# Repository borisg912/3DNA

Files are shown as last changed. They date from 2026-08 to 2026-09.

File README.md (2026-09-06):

# 3DNA - Interactive DNA Learning Model

**3DNA** is an educational 3D-printed DNA model that combines physical structure with interactive electronics to help students understand DNA base pairing through hands-on learning.

**Website**: [Project showcase and app downloads](Website)

## 🧬 Project Overview

This project creates a flat cylindrical DNA model with:
- **Magnetic DNA bases** with color-coded NeoPixel LEDs and unique resistor values for identification
- **Interactive base pairing game** that validates correct DNA base connections
- **Smart home integration** with multiple connectivity options
- **Companion applications** for Android and Windows

## 📦 Components

### Hardware
- **ESP32-C6** microcontroller on custom PCB (3-3.3V logic)
- **13 DNA bases** (12 helix positions + 1 foundation) with NeoPixels and resistors
- **2x CD74HC4067 multiplexers**: one at 3.3V for resistor voltage divider, one at 5V for NeoPixel control
- **SN74AHCT125N** buffer gate for driving 5V signals from ESP32's 3V
- **TEMT6000** ambient light sensor for dynamic brightness control
- **MPU-6500** gyroscope/inclinometer for spatial orientation
- **DFPlayer Mini** for audio feedback
- **BQ25895** power management IC with USB/USB-C quick charging (up to 9V, 25W@3A)
- **MP8715** voltage regulator (5-9V to 5V)
- **4x 18650 Li-ion batteries** (user-replaceable) with per-cell protection: PPTC fuses + AO3401A + DW01 + FS8205A
- **FQP30N06L** MOSFET for fan control
- **BAT54C** Schottky diode
- **NeoPixel strips** for visual effects (5V)
- **Touch button** for user interaction
- **Backboard button** for system functions

### Software
- **ESP-IDF firmware** for ESP32-C6
- **Android application** for mobile control
- **Windows UWP application** for desktop

## 🎯 Features

### Interactive Learning Mode
- **Base Identification**: Each base has a unique resistor value read via voltage divider
- **Color Coding**: NeoPixels light up in base-specific colors (A, T, C, G)
- **Pair Validation**: Check correct base pairing (A-T, C-G) with visual feedback
- **Error Highlighting**: Wrong bases light up in red for easy identification

### Smart Home Mode
- **Multi-protocol connectivity**: Wi-Fi, Bluetooth/BLE, Zigbee, Thread
- **Remote control**: Control NeoPixels via companion apps
- **Motion sensing**: Gyroscope triggers commands on movement
- **Ambient lighting**: Dynamic brightness based on environment

### Power Management
- **Battery operation**: 2-4 cell configuration
- **USB charging**: With power delivery management
- **Sleep modes**: Low-power states for battery conservation
- **Thermal management**: Fan control based on temperature

## 🛠️ Development Status

- **Hardware**: PCB design in KiCad (v4.1 final)
- **Firmware**: ESP-IDF framework with modular components
- **Mobile**: Android app foundation
- **Desktop**: Windows UWP app starter

## 📁 Project Structure

```
3DNA/
├── Embedded/          KiCad PCB files
├── EmbeddedCode/      ESP32-C6 firmware (ESP-IDF)
├── AppAndroid/        Android mobile app
├── AppWindows/        Windows UWP desktop app
├── Website/           Project showcase website
└── Assets/            Graphics and media
```

## 📄 Documentation

- [English README](README.md)
- [Български README](README.BG.md)

## 🤝 Contributing

This is a school project developed for educational purposes. Contributions and feedback are welcome for improving the learning experience and technical implementation.

## 📜 License

This project is licensed under **GNU GPL v3** - see [LICENSE](LICENSE) for details.

---

*Built with passion for education and technology*

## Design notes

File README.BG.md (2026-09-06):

# 3DNA - Интерактивен ДНК Модел за Учене

**3DNA** е образователен 3D-отпечатан модел на ДНК, който комбинира физическа структура с интерактивна електроника, за да помага на учениците да разберат свързването на ДНК базите чрез практично обучение.

**Уебсайт**: [Проектна витрина и изтегляне на приложения](Website)

## 🧬 Общ Преглед на Проекта

Този проект създава плосък цилиндричен ДНК модел с:
- **Магнитни ДНК бази** с цветно кодирани NeoPixel LED-ове и уникални резисторни стойности за идентификация
- **Интерактивна игра за свързване на бази** за валидиране на правилните ДНК свързвания
- **Интеграция със smart home** с множество опции за свързване
- **Съпътстващи приложения** за Android и Windows

## 📦 Компоненти

### ХARDWARE
- **ESP32-C6** микроконтролер на персонализирана PCB (3-3.3V логика)
- **13 ДНК бази** (12 позиции на хеликс + 1 основа) с NeoPixel-и и резистори
- **2x CD74HC4067 мултиплексора**: един на 3.3V за voltage divider на резистори, един на 5V за контрол на NeoPixel
- **SN74AHCT125N** буферен gate за задвижване на 5V сигнали от 3V на ESP32
- **TEMT6000** сензор за околна светлина за динамично régлиране на яркостта
- **MPU-6500** жироскоп/инклинометър за пространствена ориентация
- **DFPlayer Mini** за аудио обратна връзка
- **BQ25895** интегрирана схема за управление на захранването с бързо зареждане чрез USB/USB-C (до 9V, 25W@3A)
- **MP8715** стабилизатор на напрежение (5-9V към 5V)
- **4x 18650 Li-ion батерии** (с възможност за смяна от потребителя) с защита на всяка батерия: PPTC предпазители + AO3401A + DW01 + FS8205A
- **FQP30N06L** MOSFET за контрол на вентилатора
- **BAT54C** Schottky диод
- **NeoPixel ленти** за визуални ефекти (5V)
- **Докосвателно бутонче** за потребителско взаимодействие
- **Backboard бутон** за системни функции

### SOFTWARE
- **Фирмуер на ESP-IDF** за ESP32-C6
- **Android приложение** за мобилен контрол
- **Windows UWP приложение** за десктоп

## 🎯 Функции

### Интерактивен Режим за Учене
- **Идентификация на Базите**: Всеки баз има уникална резисторна стойност, която се чете чрез voltage divider
- **Цветно Кодиране**: NeoPixel-ите светят в специфични цветове за всеки баз (A, T, C, G)
- **Валидация на Двойките**: Проверка за правилно свързване на базите (A-T, C-G) с визуална обратна връзка
- **Отбелязване на Грешки**: Грешните бази светят в червено за лесно идентифициране

### Smart Home Режим
- **Мулти-протоколна свързаност**: Wi-Fi, Bluetooth/BLE, Zigbee, Thread
- **Дистанционно управление**: Контрол на NeoPixel-ите чрез съпътстващи приложения
- **Разпознаване на Движение**: Жироскопът активира команди при движение
- **Амбиентно осветление**: Динамична яркост въз основа на околната светлина

### Управление на захранването
- **Работа с батерии**: Конфигурация с 2-4 клетки
- **USB зареждане**: С управление на захранването
- **Режими на спиране**: Нискоенергийни състояния за икономия на батерията
- **Термално управление**: Контрол на вентилатора въз основа на температурата

## 🛠️ Статус на Развитие

- **Хардвер**: Дизайн на PCB в KiCad (v4.1 финална версия)
- **Фирмуер**: ESP-IDF рамка с модулни компоненти
- **Мобилно приложение**: Основни основи за Android
- **Десктоп приложение**: Начална версия за Windows UWP

## 📁 Структура на Проекта

```
3DNA/
├── Embedded/           # KiCad файлове за PCB
├── EmbeddedCode/      # Фирмуер за ESP32-C6 (ESP-IDF)
├── AppAndroid/        # Android мобилно приложение
├── AppWindows/        # Windows UWP десктоп приложение
├── Website/           # Уебсайт на проекта
└── Assets/            # Графика и мултимедия
```

## 📄 Документация

- [English README](README.md)
- [Български README](README.BG.md)

## 🤝 Приноси

Това е училищен проект, разработен за образователни цели. Приветстват се приноси и обратна връзка за подобряване на образователния опит и техническата реализация.

## 📜 Лиценз

Този проект е лицензиран под **GNU GPL v3** - вижте [LICENSE](LICENSE) за повече детайли.

---

*Изграден с страст към образованието и технологиите*

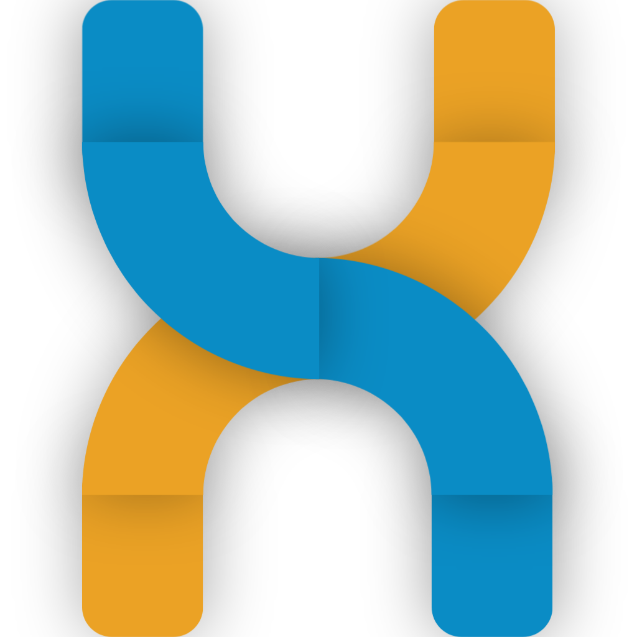
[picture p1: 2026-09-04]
Assets/Light.png

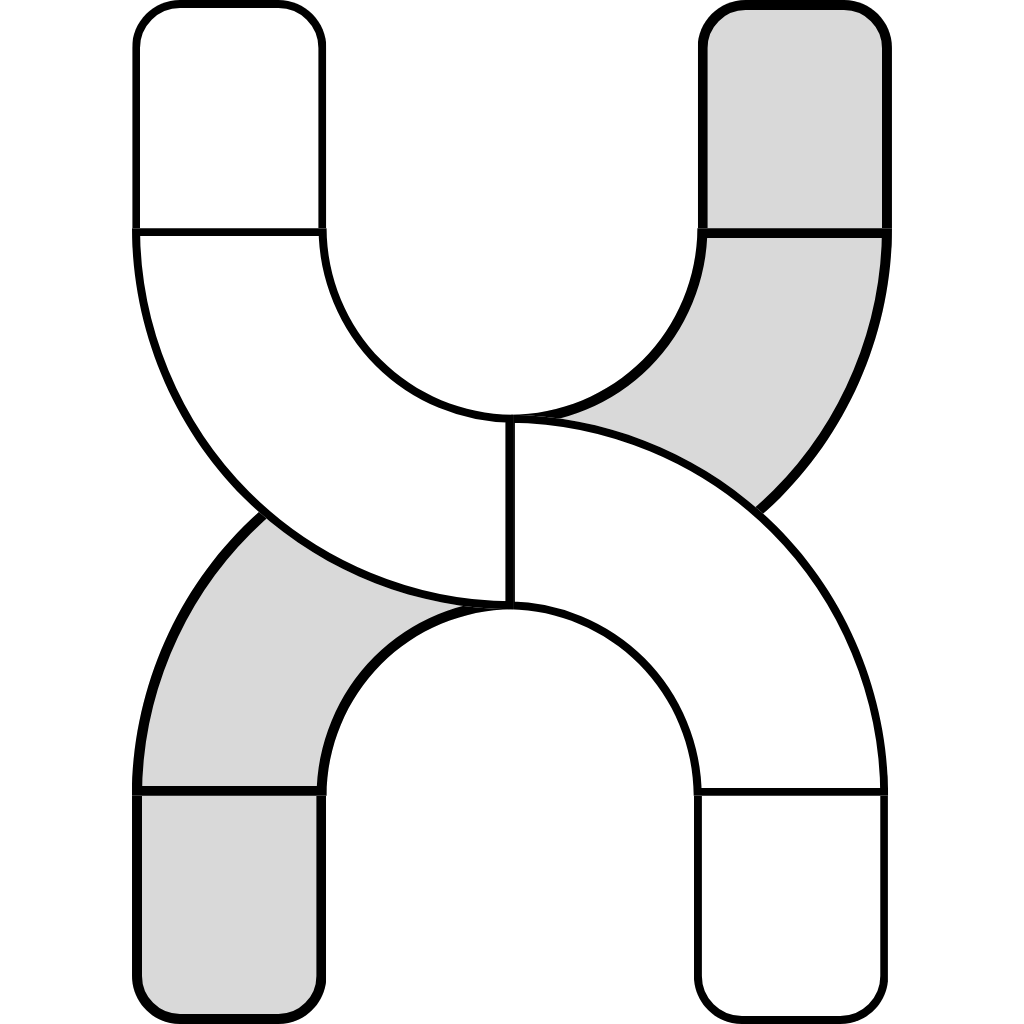
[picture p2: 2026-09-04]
Assets/Black.png

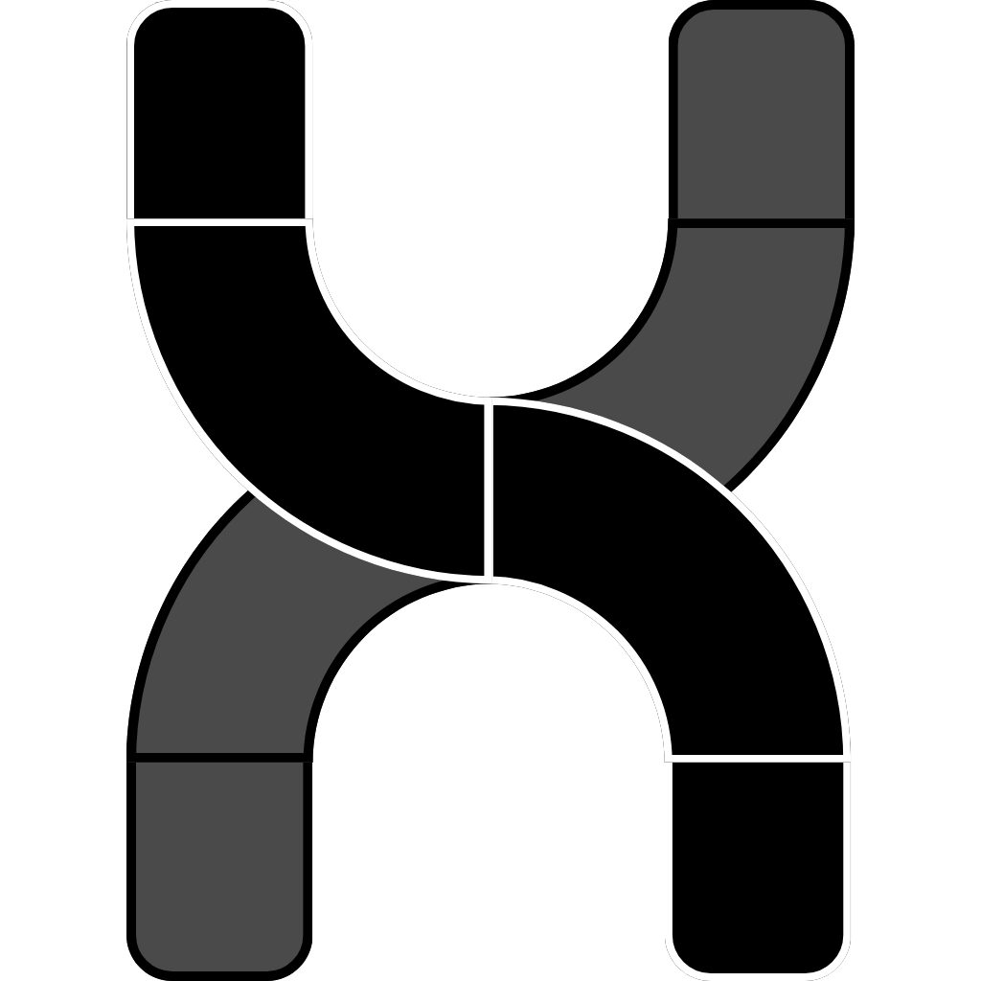
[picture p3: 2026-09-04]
Assets/White.png

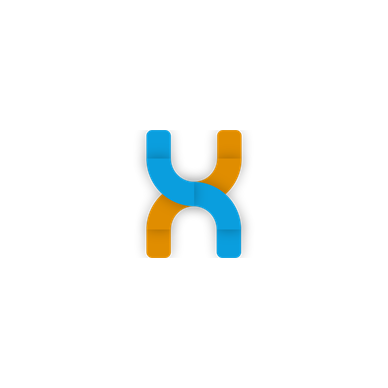
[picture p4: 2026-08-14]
AppWindows/AssetsMigrate/LargeTile.scale-125.png

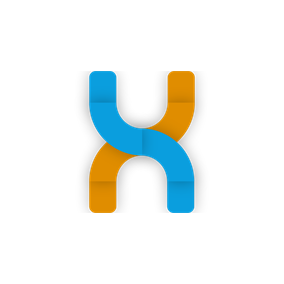
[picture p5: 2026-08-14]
AppWindows/AssetsMigrate/SmallTile.scale-400.png

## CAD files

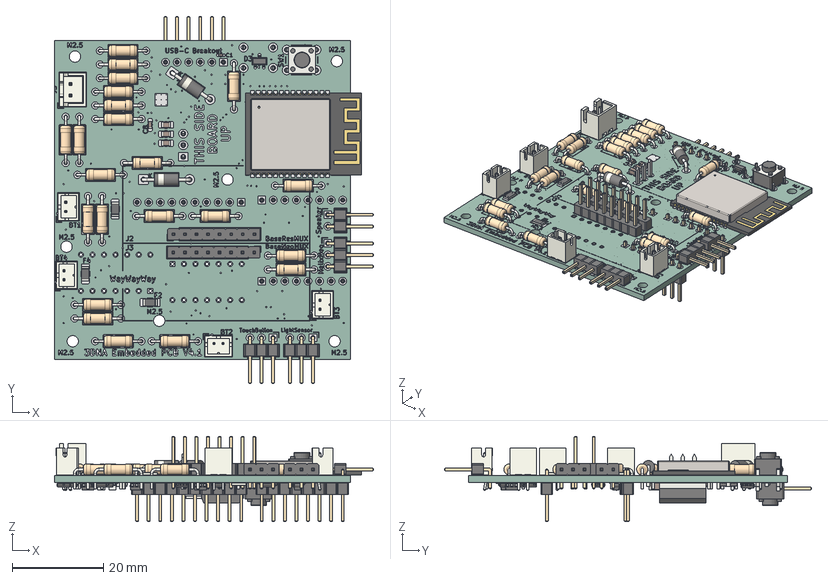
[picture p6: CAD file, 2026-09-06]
BoardModel.step
70.0 x 80.6 x 18.8 mm
R_Axial_DIN0207_L63mm_D25mm_P1016mm_Horizontal x 22
D_DO-41_SOD81_P10.16mm_Horizontal x 2
C_0402_1005Metric x 7
C_0805_2012Metric x 3
JST_B2B_PH_K x 4
PinHeader_1x03_P254mm_Horizontal x 3
C_0603_1608Metric x 6
PinHeader_1x08_P254mm_Vertical x 4
JST_B2B_XH_A
uid__2428
MINI-ANT-TYPEB.STEP
R0201_20210301.xtd x 9
ESP32-C6_QFN40_5X5_202306.xtd
XTAL3225_20210301.xtd
SOP8_rev1_20210308.xtd
L0201_20210301.xtd x 2
DFN1006.xtd
C0402_20210301.xtd
C0201_20210301.xtd x 13
Imported
ESP32-WROOM-32D_shielding_case_
Fuse_1206_3216Metric x 4
SW_PUSH_6mm_h5mm x 2
PinHeader_1x02_P254mm_Horizontal
SOT-23
MSOP-8_3x3mm_P0.65mm x 4
PinHeader_1x06_P254mm_Horizontal
SOT-23-6 x 4
PinHeader_1x10_P254mm_Vertical
TSOT-23 x 4
C_1206_3216Metric x 2
Texas_RTW_WQFN-24-1EP_4x4mm_P0.5mm_EP2.7x2.7mm
TO-220-3_Horizontal_TabDown
MSOP-10_3x3mm_P0.5mm
Emb4529_pad
Emb4529_silkscreen x 2
Emb4529_PCB

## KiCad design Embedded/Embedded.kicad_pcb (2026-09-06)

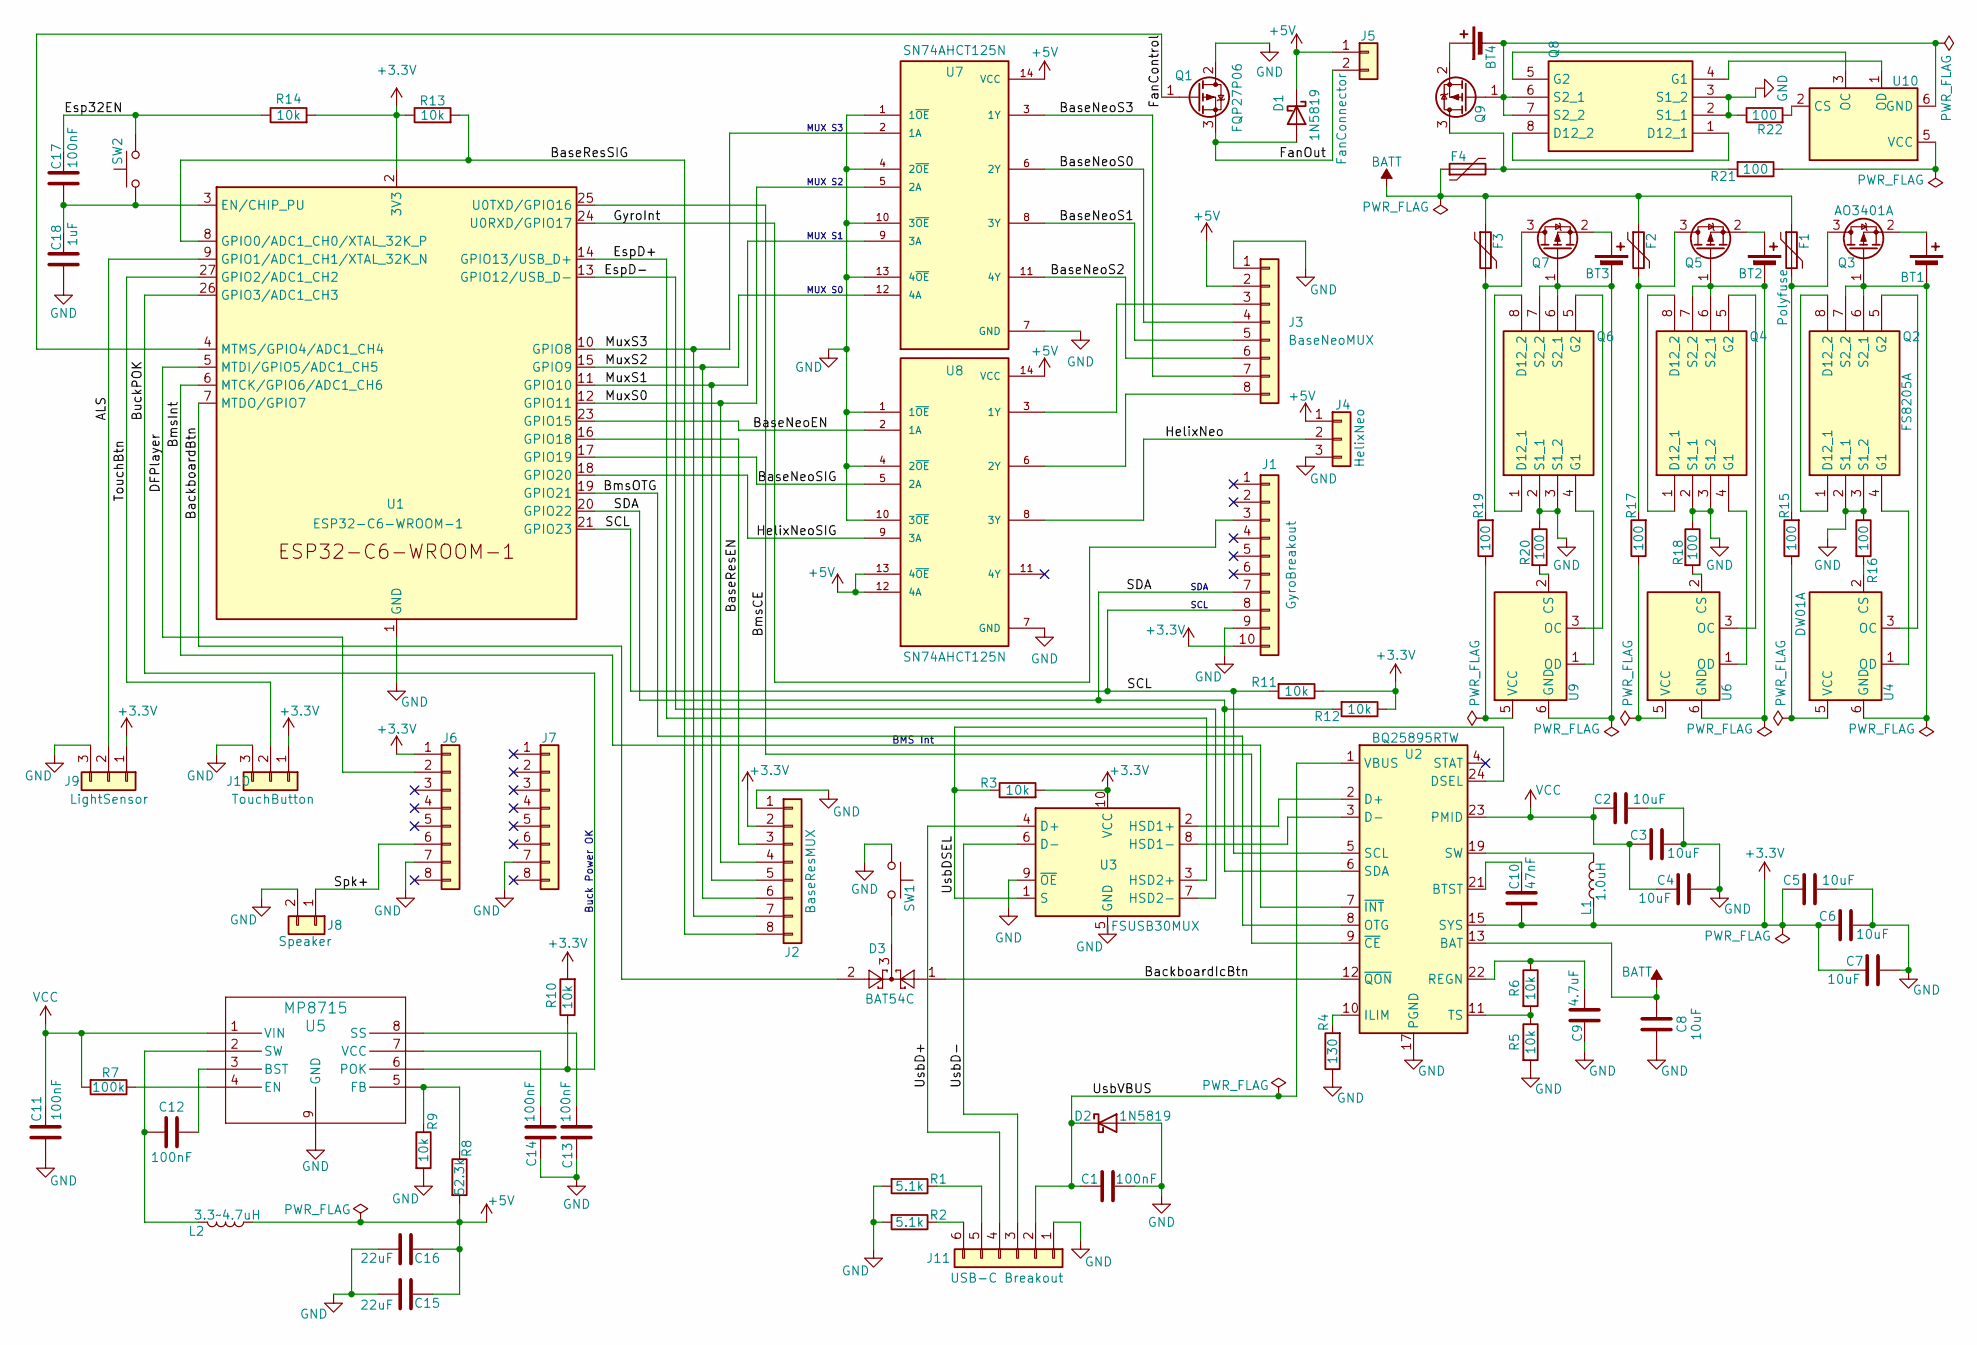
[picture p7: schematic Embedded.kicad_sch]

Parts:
BT1, BT2, BT3, BT4: Battery_Cell; JST_PH_B2B-PH-K_1x02_P2.00mm_Vertical
C1, C11, C12, C13, C14, C17: 100nF; C_0402_1005Metric_Pad0.74x0.62mm_HandSolder
C2, C3, C4: 10uF; C_0805_2012Metric_Pad1.18x1.45mm_HandSolder
C5, C6, C7, C8: 10uF; C_0603_1608Metric_Pad1.08x0.95mm_HandSolder
C9: 4.7uF; C_0603_1608Metric_Pad1.08x0.95mm_HandSolder
C10: 47nF; C_0402_1005Metric_Pad0.74x0.62mm_HandSolder
C15, C16: 22uF; C_1206_3216Metric_Pad1.33x1.80mm_HandSolder
C18: 1uF; C_0603_1608Metric_Pad1.08x0.95mm_HandSolder
D1, D2: 1N5819; D_DO-41_SOD81_P10.16mm_Horizontal
D3: BAT54C; SOT-23
F1, F2, F3, F4: Polyfuse; Fuse_1206_3216Metric_Pad1.42x1.75mm_HandSolder
J1: GyroBreakout; PinHeader_1x10_P2.54mm_Vertical
J2: BaseResMUX; PinHeader_1x08_P2.54mm_Vertical
J3: BaseNeoMUX; PinHeader_1x08_P2.54mm_Vertical
J4: HelixNeo; PinHeader_1x03_P2.54mm_Horizontal
J5: FanConnector; PinHeader_1x02_P2.54mm_Horizontal
J6, J7: Conn_01x08; PinHeader_1x08_P2.54mm_Vertical
J8: Speaker; PinHeader_1x02_P2.54mm_Horizontal
J9: LightSensor; PinHeader_1x03_P2.54mm_Horizontal
J10: TouchButton; PinHeader_1x03_P2.54mm_Horizontal
J11: USB-C Breakout; PinHeader_1x06_P2.54mm_Horizontal
L1: 1.0uH; L_Ferrocore_DLG-0403
L2: 3.3~4.7uH; L_Ferrocore_DLG-0403
Q1: FQP27P06; TO-220-3_Horizontal_TabDown
Q2, Q4, Q6, Q8: FS8205A; MSOP-8_3x3mm_P0.65mm; Manufacturer_Part_Number FS8205A
Q3, Q5, Q7, Q9: AO3401A; TSOT-23_HandSoldering
R1, R2: 5.1k; R_Axial_DIN0207_L6.3mm_D2.5mm_P10.16mm_Horizontal
R3, R5, R6, R9, R10, R11, R12, R13, R14: 10k; R_Axial_DIN0207_L6.3mm_D2.5mm_P10.16mm_Horizontal
R4: 130; R_Axial_DIN0207_L6.3mm_D2.5mm_P10.16mm_Horizontal
R7: 100k; R_Axial_DIN0207_L6.3mm_D2.5mm_P10.16mm_Horizontal
R8: 52.3k; R_Axial_DIN0207_L6.3mm_D2.5mm_P10.16mm_Horizontal
R15, R16, R17, R18, R19, R20, R21, R22: 100; R_Axial_DIN0207_L6.3mm_D2.5mm_P10.16mm_Horizontal
SW1, SW2: BackboardSw; SW_PUSH_6mm_H5mm
U1: ESP32-C6-WROOM-1
U2: BQ25895RTW; Texas_RTW_WQFN-24-1EP_4x4mm_P0.5mm_EP2.7x2.7mm_ThermalVias
U3: FSUSB30MUX; MSOP-10_3x3mm_P0.5mm
U4, U6, U9, U10: DW01A; SOT-23-6
U5: MP8715; SOIC8_MP8001A_MNP
U7, U8: SN74AHCT125N; DIP794W45P254L1930H508Q14; PARTREV Q

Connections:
+3.3V: C5.1, C6.2, C7.1, C10.1, J1.10, J2.2, J6.1, J9.1, J10.1, L1.1, R3.2, R10.2, R11.1, R12.1, R13.1, R14.2, U1.2 (3V3), U2.15 (SYS), U2.16 (SYS), U3.10 (VCC)
+5V: C15.1, C16.1, D1.1 (K), J3.2, J4.1, J5.1, L2.1, R8.2, U7.14 (VCC), U8.12 (4A), U8.13 (4~OE), U8.14 (VCC)
/ALS: J9.2, U1.9 (GPIO1/ADC1_CH1/XTAL_32K_N)
/BackboardBtn: D3.2, U1.7 (MTDO/GPIO7)
/BackboardIcBtn: D3.1, U2.12 (~QON)
/BaseNeoEN: U1.23 (GPIO15), U8.2 (1A)
/BaseNeoS0: J3.4, U7.6 (2Y)
/BaseNeoS1: J3.5, U7.8 (3Y)
/BaseNeoS2: J3.6, U7.11 (4Y)
/BaseNeoS3: J3.7, U7.3 (1Y)
/BaseNeoSIG: U1.17 (GPIO19), U8.5 (2A)
/BaseResEN: J2.3, U1.16 (GPIO18)
/BaseResSIG: J2.8, R13.2, U1.8 (GPIO0/ADC1_CH0/XTAL_32K_P)
/BmsCE: U1.25 (U0TXD/GPIO16), U2.9 (~CE)
/BmsInt: U1.6 (MTCK/GPIO6/ADC1_CH6), U2.7 (~INT)
/BmsOTG: U1.19 (GPIO21), U2.8 (OTG)
/BuckPOK: R10.1, U1.26 (GPIO3/ADC1_CH3), U5.6 (POK)
/DFPlayer: J6.2, U1.5 (MTDI/GPIO5/ADC1_CH5)
/Esp32EN: C17.2, R14.1, SW2.2
/EspD+: U1.14 (GPIO13/USB_D+), U3.3 (HSD2+)
/EspD-: U1.13 (GPIO12/USB_D-), U3.7 (HSD2-)
/FanControl: Q1.1 (G), U1.4 (MTMS/GPIO4/ADC1_CH4)
/FanOut: D1.2 (A), J5.2, Q1.3 (S)
/GyroInt: J1.3, U1.24 (U0RXD/GPIO17)
/HelixNeo: J4.2, U8.8 (3Y)
/HelixNeoSIG: U1.18 (GPIO20), U8.9 (3A)
/MuxS0: J2.4, U1.12 (GPIO11), U7.5 (2A)
/MuxS1: J2.5, U1.11 (GPIO10), U7.9 (3A)
/MuxS2: J2.6, U1.15 (GPIO9), U7.12 (4A)
/MuxS3: J2.7, U1.10 (GPIO8), U7.2 (1A)
/SCL: J1.8, R11.2, U1.21 (GPIO23), U2.5 (SCL)
/SDA: J1.7, R12.2, U1.20 (GPIO22), U2.6 (SDA)
/Spk+: J6.6, J8.1
/TouchBtn: J10.2, U1.27 (GPIO2/ADC1_CH2)
/UsbD+: J11.4, U3.4 (D+)
/UsbD-: J11.3, U3.6 (D-)
/UsbDSEL: R3.1, U2.24 (DSEL), U3.1 (S)
/UsbVBUS: C1.1, D2.1 (K), J11.2, U2.1 (VBUS)
BATT: C8.2, F1.1, F2.1, F3.1, F4.1, U2.13 (BAT), U2.14 (BAT)
GND: C1.2, C2.2, C3.1, C4.2, C5.2, C6.1, C7.2, C8.1, C9.1, C11.1, C13.2, C14.2, C15.2, C16.2, C18.1, D2.2 (A), J1.9, J2.1, J3.1, J4.3, J6.7, J7.7 (Pin_7_7), J8.2, J9.3, J10.3, J11.1, Q1.2 (D), Q2.2 (S1_1), Q2.3 (S1_2), Q4.2 (S1_1), Q4.3 (S1_2), Q6.2 (S1_1), Q6.3 (S1_2), Q8.2 (S1_1), Q8.3 (S1_2), R1.2, R2.2, R4.1, R5.2, R9.2, R16.1, R18.1, R20.1, R22.1, SW1.1, U1.1 (GND), U1.28 (GND), U1.29 (GND), U2.17 (PGND), U2.18 (PGND), U2.25 (PGND), U3.5 (GND), U3.9 (~OE), U5.9 (GND), U7.1 (1~OE), U7.4 (2~OE), U7.7 (GND), U7.10 (3~OE), U7.13 (4~OE), U8.1 (1~OE), U8.4 (2~OE), U8.7 (GND), U8.10 (3~OE)
unnamed: BT1.1 (+), Q3.2 (S)
unnamed: BT1.2 (-), Q2.6 (S2_1), Q2.7 (S2_2), Q3.1 (G), U4.6 (GND)
unnamed: BT2.1 (+), Q5.2 (S)
unnamed: BT2.2 (-), Q4.6 (S2_1), Q4.7 (S2_2), Q5.1 (G), U6.6 (GND)
unnamed: BT3.1 (+), Q7.2 (S)
unnamed: BT3.2 (-), Q6.6 (S2_1), Q6.7 (S2_2), Q7.1 (G), U9.6 (GND)
unnamed: BT4.1 (+), Q9.2 (S)
unnamed: BT4.2 (-), Q8.6 (S2_1), Q8.7 (S2_2), Q9.1 (G), U10.6 (GND)
unnamed: D3.3, SW1.2
unnamed: J3.3, U8.3 (1Y)
unnamed: J3.8, U8.6 (2Y)
unnamed: J11.5, R1.1
unnamed: J11.6, R2.1
unnamed: L1.2, U2.19 (SW), U2.20 (SW)
unnamed: Q2.1 (D12_1), Q2.8 (D12_2)
unnamed: Q2.4 (G1), U4.1 (OD)
unnamed: Q2.5 (G2), U4.3 (OC)
unnamed: F1.2, Q3.3 (D), R15.2
unnamed: Q4.1 (D12_1), Q4.8 (D12_2)
unnamed: Q4.4 (G1), U6.1 (OD)
unnamed: Q4.5 (G2), U6.3 (OC)
unnamed: F2.2, Q5.3 (D), R17.2
unnamed: Q6.1 (D12_1), Q6.8 (D12_2)
unnamed: Q6.4 (G1), U9.1 (OD)
unnamed: Q6.5 (G2), U9.3 (OC)
unnamed: F3.2, Q7.3 (D), R19.2
unnamed: Q8.1 (D12_1), Q8.8 (D12_2)
unnamed: Q8.4 (G1), U10.1 (OD)
unnamed: Q8.5 (G2), U10.3 (OC)
unnamed: F4.2, Q9.3 (D), R21.2
unnamed: C17.1, C18.2, SW2.1, U1.3 (EN/CHIP_PU)
unnamed: C10.2, U2.21 (BTST)
unnamed: U2.2 (D+), U3.2 (HSD1+)
unnamed: U2.3 (D-), U3.8 (HSD1-)
unnamed: R4.2, U2.10 (ILIM)
unnamed: C9.2, R6.1, U2.22 (REGN)
unnamed: R5.1, R6.2, U2.11 (TS)
unnamed: R16.2, U4.2 (CS)
unnamed: R15.1, U4.5 (VCC)
unnamed: C12.2, U5.3 (BST)
unnamed: R7.1, U5.4 (EN)
unnamed: R8.1, R9.1, U5.5 (FB)
unnamed: C13.1, U5.8 (SS)
unnamed: C12.1, L2.2, U5.2 (SW)
unnamed: C14.1, U5.7 (VCC)
unnamed: R18.2, U6.2 (CS)
unnamed: R17.1, U6.5 (VCC)
unnamed: R20.2, U9.2 (CS)
unnamed: R19.1, U9.5 (VCC)
unnamed: R22.2, U10.2 (CS)
unnamed: R21.1, U10.5 (VCC)
VCC: C2.1, C3.2, C4.1, C11.2, R7.2, U2.23 (PMID), U5.1 (VIN)

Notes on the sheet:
SCL
SDA
MUX S3
MUX S2
BMS Int
Buck Power OK
MUX S1
MUX S0

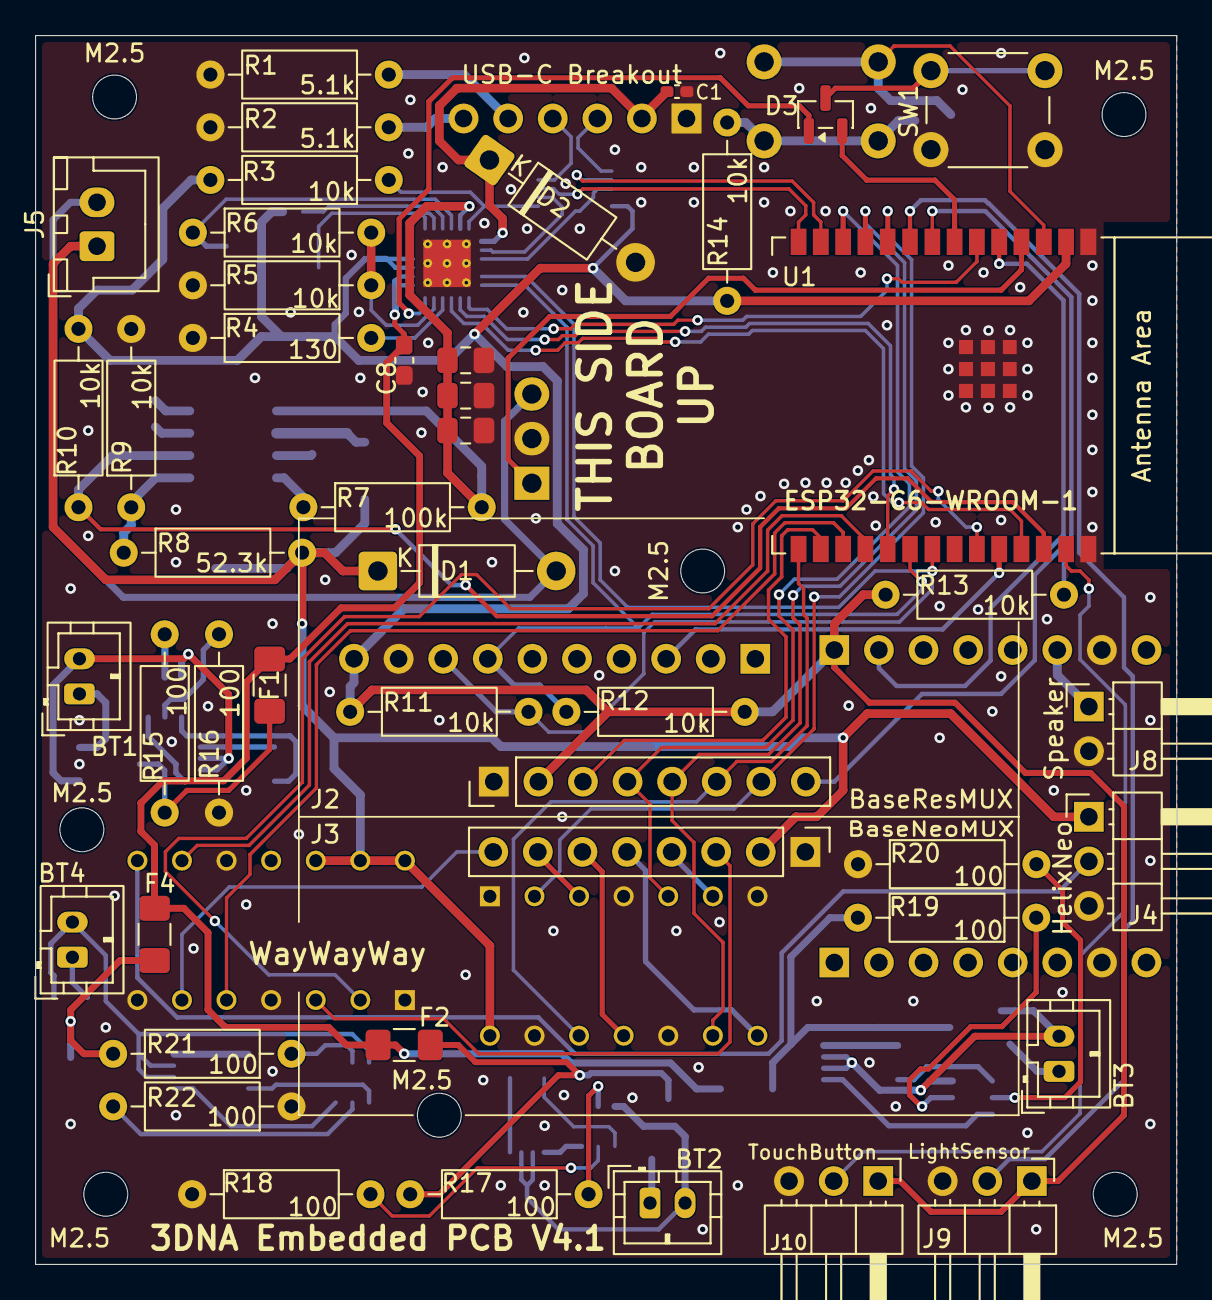
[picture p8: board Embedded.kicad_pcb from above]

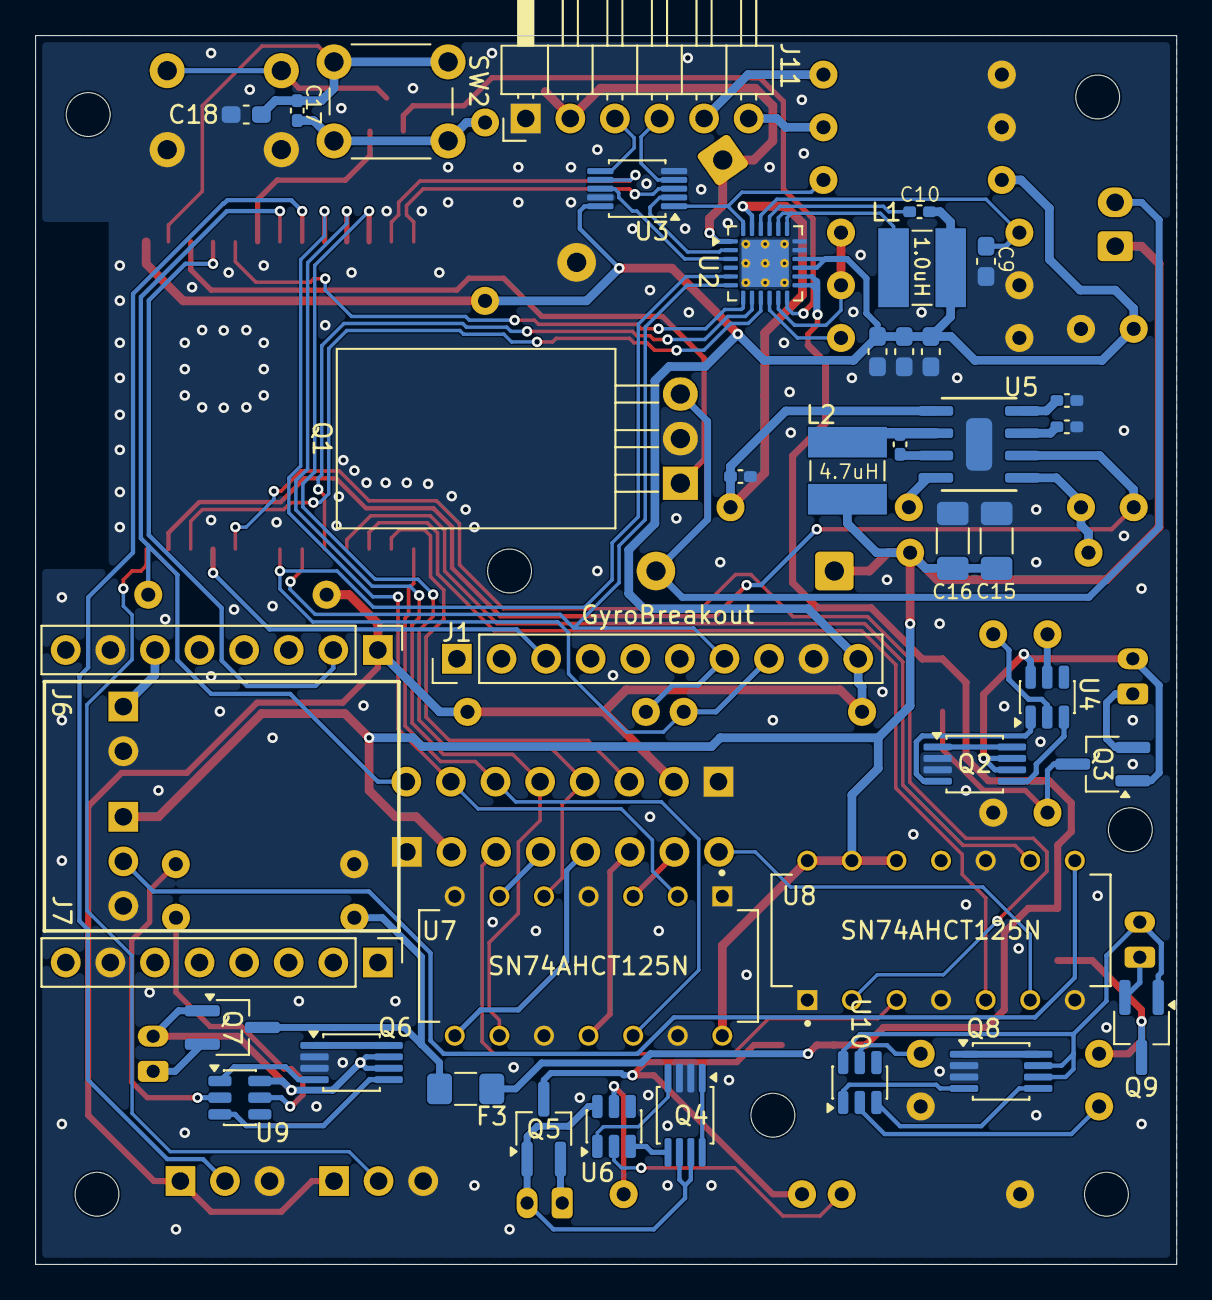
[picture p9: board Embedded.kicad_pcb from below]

Board: 2 copper layers, 65.0 x 70.0 mm, 92 parts (39 on the bottom side), 92 nets.

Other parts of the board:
M2.5, M2.5#2, M2.5#3, M2.5#4, M2.5#5, M2.5#6, M2.5#7: MountingHole_2.5mm

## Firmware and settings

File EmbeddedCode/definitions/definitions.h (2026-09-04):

#pragma once

#include "driver/gpio.h"
#include "esp_adc/adc_oneshot.h"

// General
#define DnaBaseCount 13     /* 12 helix slots + 1 foundation slot */

// I2C bus
#define I2cSda  22
#define I2cScl  23
#define I2cFreq 100000

// BQ25895
#define BmsInt    6
#define BmsOtg    21
#define BmsCe     16
#define BuckPwrOK 3

// Base Multiplexers (address bits shared by both MUXes)
#define MuxS0          11
#define MuxS1          10
#define MuxS2          9
#define MuxS3          8
#define MuxResEn       18
#define MuxResOut      0
#define MuxResAdcChan  ADC_CHANNEL_0   /* ADC1_CH0 -> GPIO0 */
#define MuxNeoPixelEn  15
#define MuxNeoPixelOut 19

// Sensors
#define LightSensor  1
#define LightAdcChan ADC_CHANNEL_1   /* ADC1_CH1 -> GPIO1 */
#define GyroInt      17

// Helix NeoPixels
#define HelixNeoPixelOut   20
#define HelixNeoPixelCount 40

// Inputs/Outputs
#define TouchButton     2
#define BackboardButton 7
#define AudioPlayerTx   5

// Other
#define FanControl 4

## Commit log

2026-08-16 small changes, big dreams
    [Embedded.kicad_pcb, Embedded.kicad_sch]
2026-08-19 Old model, new connectors
    [Board.step, BoardModel.step, Embedded.kicad_pcb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]
2026-08-24 v4.1, final pcb
    [Embedded.kicad_pcb]
2026-09-04 Overhaul
    Redesign, Ground for UWP/Droid app, Switch from Arduino C to ESP-IDF with native C
    [BoardModel.step, Embedded.kicad_pcb, Embedded.kicad_sch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]
2026-09-06 PCB changes + new readme
    [BoardModel.step, Embedded.kicad_pcb]
